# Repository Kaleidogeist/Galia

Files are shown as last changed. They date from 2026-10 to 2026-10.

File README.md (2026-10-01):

# Galia
Modular split ergonomic keyboard system with each half consisting of a central motherboard and a hot-swappable key cluster daughterboard to allow for maximum flexibility.

### Motherboard
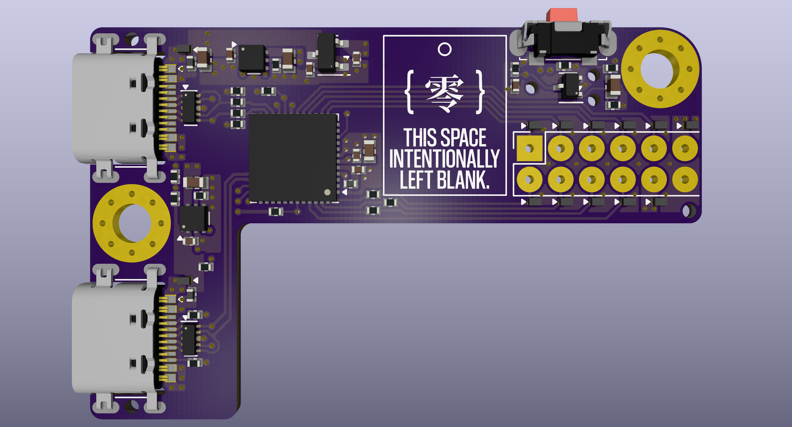
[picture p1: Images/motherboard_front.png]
Motherboard_Front

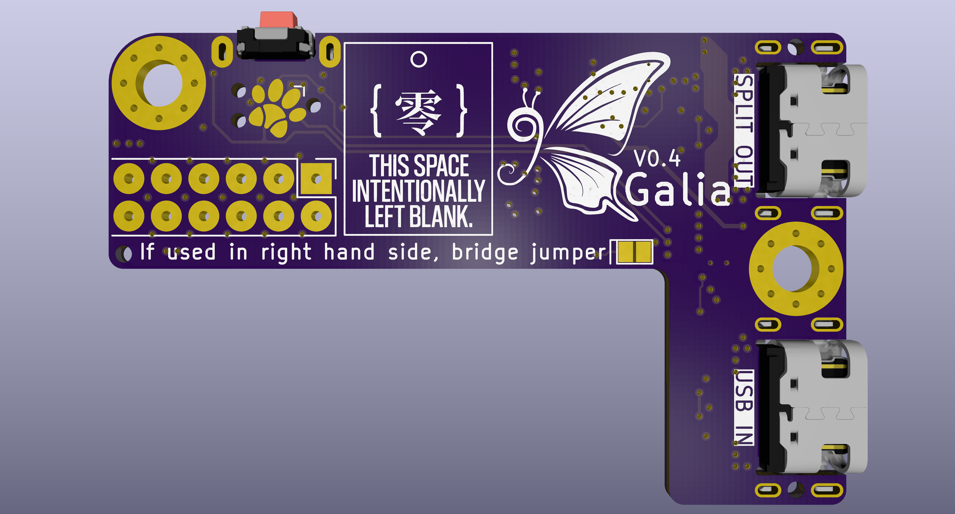
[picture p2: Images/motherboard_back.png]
Motherboard_Back

- Current version: V0.4.
- Schematic [here](https://kicanvas.org/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). 
- Board layout [here](https://kicanvas.org/?repo=https%3A%2F%2Fgithub.com%2Fghostlybutterfly%2FGalia%2Ftree%2FV0_dev%2FMotherboard).
### Daughterboard (Cantaloupe)
Current version: N/A (wip).

## Disclaimer
This keyboard is licensed under [CERN-OHL-S-2.0](https://cern-ohl.web.cern.ch/) and is compatible with both [QMK Firmware](https://qmk.fm/) and [ZMK Firmware](https://zmk.dev).

## Key Features
### Motherboard
* Fully reversible, compact (32.0x50.0mm), and designed to fit onto the top inner corner of a split keyboard.
* On-board STM32G0B1CCU7 processor.
* ESD-protected USB-C input port and USB-C split comms port.
* Connects to daughterboard through fully ESD-protected 2.54mm pitch 02x06 pogo header.
* SPI and USART lines terminated with 22ohm to reduce ringing, overshoot and EMI, and improve signal integrity.
* VBUS input rail limited to ~469mA and 5V output rail limited to ~179mA through the use of TPS2553-1 current limiting switches with reverse voltage protection. VBUS requires power cycling to restart the device upon overcurrent, +5V can be power-cycled through firmware with EN pin controlled through firmware to reduce RGB LED quiescent current draw.
* 4-layer (signal/ground/power/signal) PCB and star ground connection point in between USB port shields.
* [Paw-Connect](https://github.com/LeoDJ/Paw-Connect) TC-2030NL SWD header for debugging purposes.
* On-board single-button reset circuit.
* JLC basic assembly compatible as long as USB ports are not soldered on.

### Daughterboard (TBC)
* Matrix scan planned to be implemented through 74HC595 SIPO shift registers for low power draw and compatibility with ZMK interrupt functionality.
* Also compatible with charlieplex, duplex, and standard matrix layouts.
* WS2812 and AP102 (QMK only) LED support.
* Additional [VIK](https://github.com/sadekbaroudi/vik) header support if desired.

## Pogo header pinout
| Function/description | Pin name | Row 1 | Row 2 | Pin name | Function/description |
| --- | --- | ----- | ----- | --- | --- |
| USART2_TX/ADC1_IN2/TIM2_CH3 | A2 | GPIO1 | CS | B9 | SPI2_NSS/I2C1_SDA/USART3_RX/TIM4_CH4  |
| USART2_RX/ADC1_IN3/TIM2_CH4 | A3 | GPIO2 | SCK | B8 | SPI2_SCK/I2C1_SCL/USART3_TX/TIM4_CH3  |
| SPI1_SCK/ADC1_IN5/TIM2_CH1 | A5 | GPIO3 | MOSI  | B7 | SPI2_MOSI/I2C1_SDA/USART1_RX/TIM4_CH2 |
| SPI1_MISO/ADC1_IN6/I2C2_SDA/TIM3_CH1 | A6 | GPIO4 | MISO  | B6 | SPI2_MISO/I2C1_SCL/USART1_TX/TIM1_CH3 |
| SPI1_MOSI/ADC1_IN7/I2C2_SCL/TIM3_CH2 | A7 | GPIO5 | +5V | N/A | ~207mA max draw by daughterboard |
| 200mA max draw by this side overall  | N/A | VDD | GND | A7 | GND |

## Changelog
* 2026/10/01: Changed library name and updated paths.
* 2026/09/30: V0.4 motherboard update complete. Removed guard ring around the edge of the board. Moved reset button and pogo header down the board. Increased length back to 50mm to allow for an E73-2G4M08S1C version to be developed if desired. Simplified reset circuit - doesn't use the Acheron version anymore. Reduced number of pins in pogo header, as the largest available ones are 2x06. Pinout of pogo header changed to greatly simplify routing - no longer VIK-compliant. Signalis reference and Paw-Connect added back. Changed file structure.
* 2026/09/26: V0.3 motherboard update complete. Reduced size again, rerouted board and changed shape slightly. Removed one mounting hole and centred the other between the USB ports. Changed input fuse and external +5V output to TPS2553-1 latching power switch with reverse voltage/current protection. Removed AO3401 and LMV321 discrete reverse current protection at VBUS input. Reduced size of VBUS and VSPLIT ferrite bead and transistors in the Acheron reset circuit. Made Acheron reset circuit reach DFU faster. 
* 2026/09/21: V0.2 motherboard update complete. Significantly decreased size. GPIO3, GPIO4 and GPIO5 pins changed. Increased size of pogo pin header pads. Removed extra IO header. Replaced 2x03 2.54mm programming header and TC2030-NL with 2x05 1.27mm Samtec IDC header. Replaced reset switch with smaller Alps SKSNLP mid-mount switch. Added layer marker. Changed repository file structure.
* 2026/09/17: Fixed gap in guard rail.
* 2026/09/16: V0.1 motherboard initial commit.

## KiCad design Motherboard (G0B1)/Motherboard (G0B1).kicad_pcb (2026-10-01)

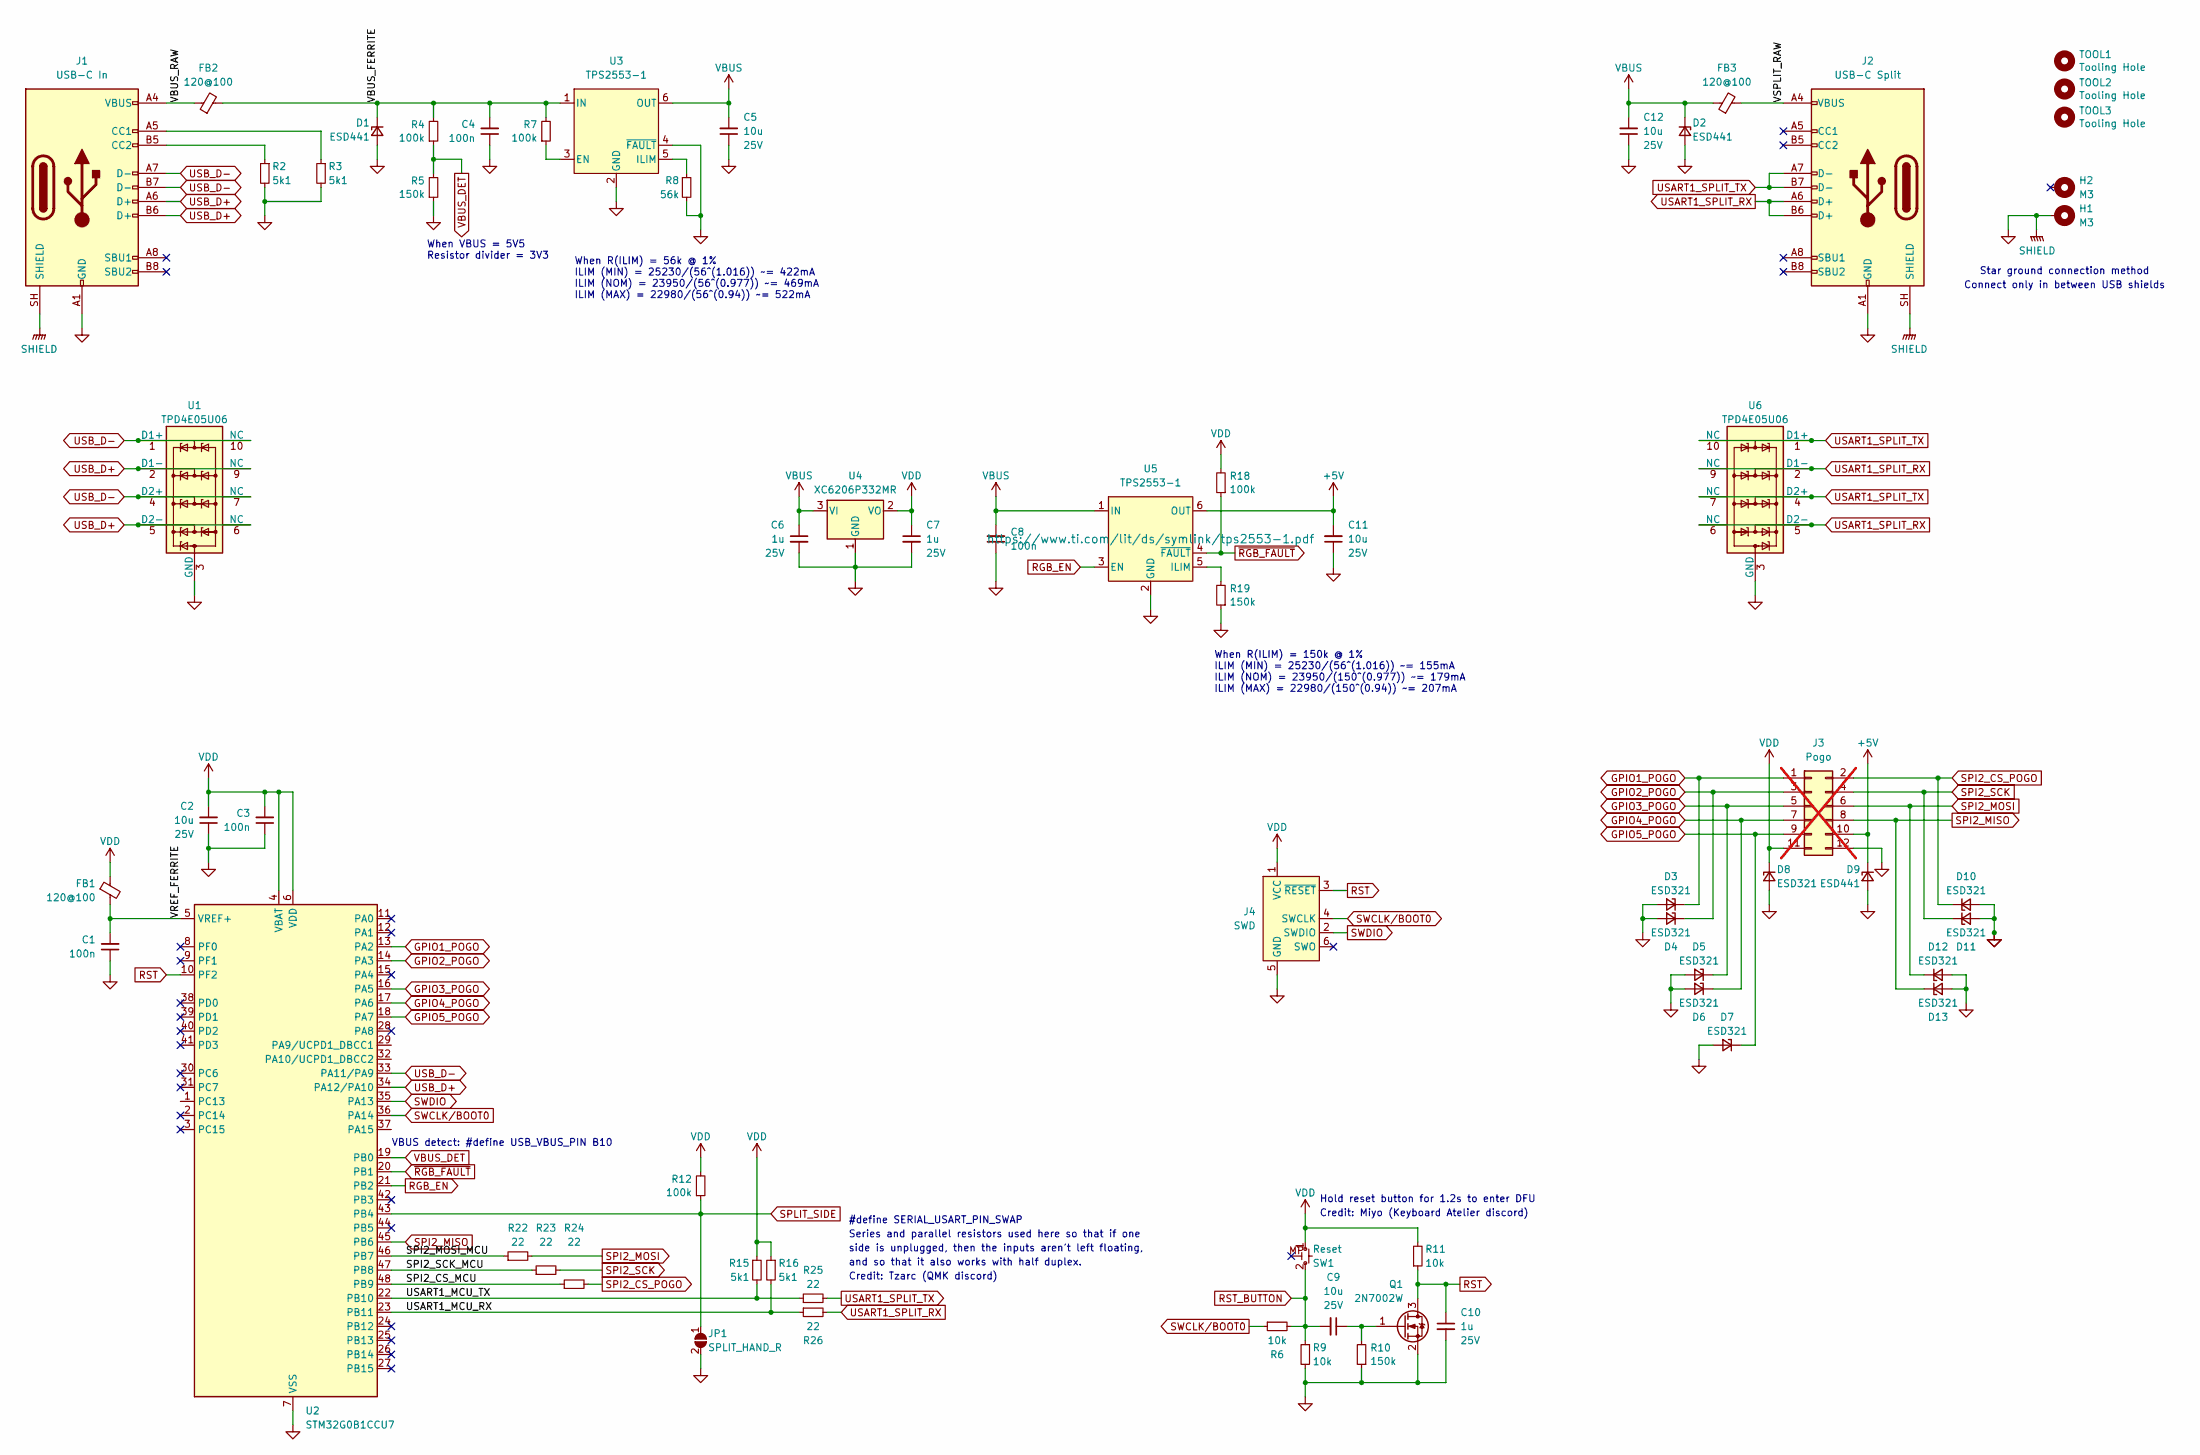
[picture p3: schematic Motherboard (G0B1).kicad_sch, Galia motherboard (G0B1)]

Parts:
C1, C3, C4, C8: 100n; C_0402_1005Metric; Rating 50V; MPN CL05B104KB54PNC; LCSC C307331
C2, C5, C9, C11, C12: 10u; C_0603_1608Metric; Rating 25V; MPN CL10A106MA8NRNC; LCSC C96446
C6, C7, C10: 1u; C_0402_1005Metric; Rating 25V; MPN CL05A105KA5NQNC; LCSC C52923
D1, D2, D9: ESD441; X1SON_0.6x1mm_P0.65mm_Texas_DPY0002A; Rating 7V breakdown; MPN ESD441DPYR; LCSC C53161160
D3, D4, D5, D6, D7, D8, D10, D11, D12, D13: ESD321; X1SON_0.6x1mm_P0.65mm_Texas_DPY0002A; Rating 4V5 breakdown; MPN ESD321DPYR; LCSC C2868952
FB1, FB2, FB3: 120@100; L_0402_1005Metric; MPN MPZ1005S121ET000; LCSC C275477
H1, H2: M3; MountingHole_3.2mm_M3_Pad_Via; MPN N/A; LCSC N/A
J1: USB-C In; USB_C_Receptacle_Molex_2169900001; MPN GT-USB-7014D; LCSC C2843969
J2: USB-C Split; USB_C_Receptacle_Molex_2169900001; MPN GT-USB-7014D; LCSC C2843969
J3: Pogo; PinHeader_2x06_2.54mm_MillMax_PogoTarget_419-10-212-00-0010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; not fitted
J4: SWD; Paw-Connect_RevB_TC2030-IDC-NL_2x03_P1.27mm_Vertical
JP1: SPLIT_HAND_R; SolderJumper-2_P1.2mm_Open_Pad1.0x1.4mm; MPN N/A; LCSC N/A
Q1: 2N7002W; SOT-323_SC-70-3; MPN 2N7002W; LCSC C7420322
R2, R3, R15, R16: 5k1; R_0402_1005Metric; MPN 0402WGF5101TCE; LCSC C25905
R4, R7, R12, R18: 100k; R_0402_1005Metric; MPN 0402WGF1003TCE; LCSC C25741
R5, R10, R19: 150k; R_0402_1005Metric; MPN 0402WGF1503TCE; LCSC C25755
R6, R9, R11: 10k; R_0402_1005Metric; MPN 0402WGF1002TCE; LCSC C25744
R8: 56k; R_0402_1005Metric; MPN 0402WGF5602TCE; LCSC C25796
R22, R23, R24, R25, R26: 22; R_0402_1005Metric; MPN 0402WGF220JTCE; LCSC C25092
SW1: Reset; SW_Alps_SKSNLM_SKSNLP; MPN SKSNLPE010; LCSC C53113391
TOOL1, TOOL2, TOOL3: Tooling Hole; MountingHole_JLC-Tooling; MPN N/A; LCSC N/A
U1, U6: TPD4E05U06; USON-10_2.5x1.0mm_P0.5mm; MPN TPD4E05U06QDQARQ1; LCSC C81353
U2: STM32G0B1CCU7; QFN-48-1EP_7x7mm_P0.5mm_EP5.6x5.6mm; MPN STM32G0B1CCU7; LCSC C29759424
U3, U5: TPS2553-1; WSON-6-1EP_2x2mm_P0.65mm_EP1x1.6mm; MPN TPS2553DRVR-1; LCSC C411878
U4: XC6206P332MR; SOT-23-3; MPN XC6206P332MR-G; LCSC C5446

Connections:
+5V: C11.2, D9.1 (K), J3.10, U5.6 (OUT)
/SPI2_CS_MCU: R24.1, U2.48 (PB9)
/SPI2_MOSI_MCU: R22.1, U2.46 (PB7)
/SPI2_SCK_MCU: R23.1, U2.47 (PB8)
/USART1_MCU_RX: R16.2, R26.1, U2.23 (PB11)
/USART1_MCU_TX: R15.2, R25.1, U2.22 (PB10)
/VBUS_FERRITE: C4.2, D1.1 (K), FB2.2, R4.2, R7.2, U3.1 (IN)
/VBUS_RAW: FB2.1, J1.A4 (VBUS), J1.A9 (VBUS), J1.B4 (VBUS), J1.B9 (VBUS)
/VREF_FERRITE: C1.2, FB1.2, U2.5 (VREF+)
/VSPLIT_RAW: FB3.2, J2.A4 (VBUS), J2.A9 (VBUS), J2.B4 (VBUS), J2.B9 (VBUS)
GND: C1.1, C2.1, C3.1, C4.1, C5.1, C6.2, C7.2, C8.1, C10.2, C11.1, C12.1, D1.2 (A), D2.2 (A), D3.2 (A), D4.2 (A), D5.2 (A), D6.2 (A), D7.2 (A), D8.2 (A), D9.2 (A), D10.2 (A), D11.2 (A), D12.2 (A), D13.2 (A), H1.1 (1_1), J1.A1 (GND), J1.A12 (GND), J1.B1 (GND), J1.B12 (GND), J1.SH (SHIELD), J2.A1 (GND), J2.A12 (GND), J2.B1 (GND), J2.B12 (GND), J2.SH (SHIELD), J3.12, J4.5 (GND), JP1.2 (B), Q1.2 (S), R2.2, R3.2, R5.1, R8.2, R9.2, R10.1, R19.1, U1.3 (GND), U1.8 (GND), U2.7 (VSS), U2.49 (VSS), U3.2 (GND), U3.4 (~FAULT), U3.7 (EP), U4.1 (GND), U5.2 (GND), U5.7 (EP), U6.3 (GND), U6.8 (GND)
GPIO1_POGO: D3.1 (K), J3.1, U2.13 (PA2)
GPIO2_POGO: D4.1 (K), J3.3, U2.14 (PA3)
GPIO3_POGO: D5.1 (K), J3.5, U2.16 (PA5)
GPIO4_POGO: D6.1 (K), J3.7, U2.17 (PA6)
GPIO5_POGO: D7.1 (K), J3.9, U2.18 (PA7)
unnamed: J1.A5 (CC1), R3.1
unnamed: J1.B5 (CC2), R2.1
unnamed: C9.1, Q1.1 (G), R10.2
unnamed: R7.1, U3.3 (EN)
unnamed: R8.1, U3.5 (ILIM)
unnamed: R19.2, U5.5 (ILIM)
RGB_EN: U2.21 (PB2), U5.3 (EN)
RST: C10.1, J4.3 (~RESET), Q1.3 (D), R11.1, U2.10 (PF2)
RST_BUTTON: C9.2, R6.2, R9.1, SW1.2 (B)
SPI2_CS_POGO: D10.1 (K), J3.2, R24.2
SPI2_MISO: D13.1 (K), J3.8, U2.45 (PB6)
SPI2_MOSI: D12.1 (K), J3.6, R22.2
SPI2_SCK: D11.1 (K), J3.4, R23.2
SPLIT_SIDE: JP1.1 (A), R12.1, U2.43 (PB4)
SWCLK/BOOT0: J4.4 (SWCLK), R6.1, U2.36 (PA14)
SWDIO: J4.2 (SWDIO), U2.35 (PA13)
USART1_SPLIT_RX: J2.A6 (D+), J2.B6 (D+), R26.2, U6.2 (D1-), U6.5 (D2-), U6.6 (NC), U6.9 (NC)
USART1_SPLIT_TX: J2.A7 (D-), J2.B7 (D-), R25.2, U6.1 (D1+), U6.4 (D2+), U6.7 (NC), U6.10 (NC)
USB_D+: J1.A6 (D+), J1.B6 (D+), U1.2 (D1-), U1.5 (D2-), U1.6 (NC), U1.9 (NC), U2.34 (PA12/PA10)
USB_D-: J1.A7 (D-), J1.B7 (D-), U1.1 (D1+), U1.4 (D2+), U1.7 (NC), U1.10 (NC), U2.33 (PA11/PA9)
VBUS: C5.2, C6.1, C8.2, C12.2, D2.1 (K), FB3.1, U3.6 (OUT), U4.3 (VI), U5.1 (IN)
VBUS_DET: R4.1, R5.2, U2.19 (PB0)
VDD: C2.2, C3.2, C7.1, D8.1 (K), FB1.1, J3.11, J4.1 (VCC), R11.2, R12.2, R15.1, R16.1, R18.2, SW1.1 (A), U2.4 (VBAT), U2.6 (VDD), U4.2 (VO)
~RGB_FAULT: R18.1, U2.20 (PB1), U5.4 (~FAULT)

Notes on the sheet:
When R(ILIM) = 56k @ 1% ILIM (MIN) = 25230/(56^(1.016)) ~= 422mA ILIM (NOM) = 23950/(56^(0.977)) ~= 469mA ILIM (MAX) = 22980/(56^(0.94)) ~= 522mA
Credit: Tzarc (QMK discord)
Hold reset button for 1.2s to enter DFU
Series and parallel resistors used here so that if one
VBUS detect: #define USB_VBUS_PIN B10
Credit: Miyo (Keyboard Atelier discord)
side is unplugged, then the inputs aren't left floating,
and so that it also works with half duplex.
When VBUS = 5V5 Resistor divider = 3V3
Connect only in between USB shields
#define SERIAL_USART_PIN_SWAP
When R(ILIM) = 150k @ 1% ILIM (MIN) = 25230/(56^(1.016)) ~= 155mA ILIM (NOM) = 23950/(150^(0.977)) ~= 179mA ILIM (MAX) = 22980/(150^(0.94)) ~= 207mA
Star ground connection method

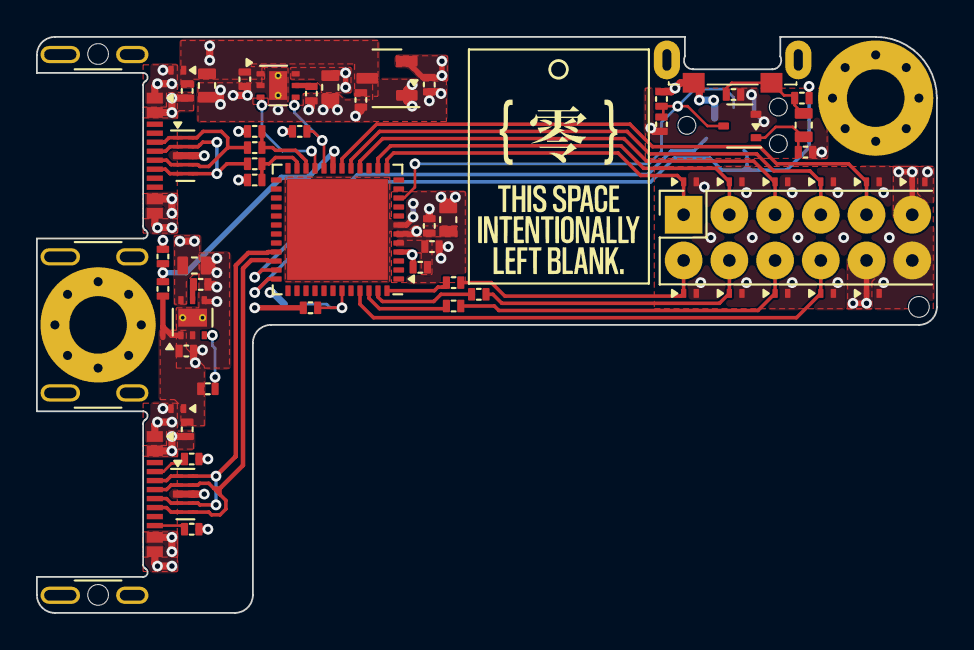
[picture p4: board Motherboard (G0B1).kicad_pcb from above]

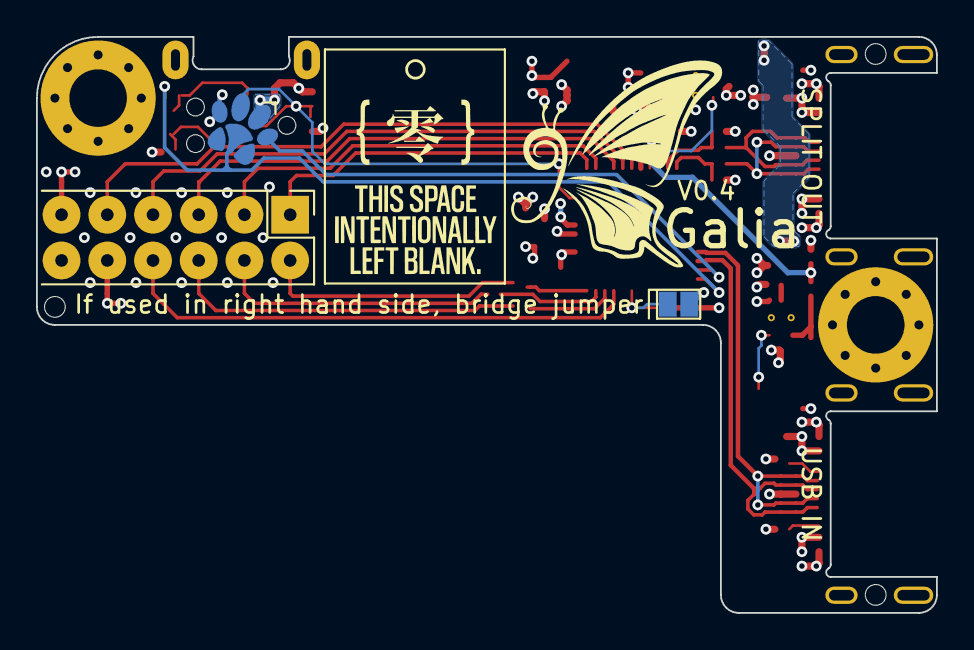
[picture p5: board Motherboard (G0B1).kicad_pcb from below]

Board: 4 copper layers, 50.0 x 32.0 mm, 66 parts (2 on the bottom side), 40 nets.

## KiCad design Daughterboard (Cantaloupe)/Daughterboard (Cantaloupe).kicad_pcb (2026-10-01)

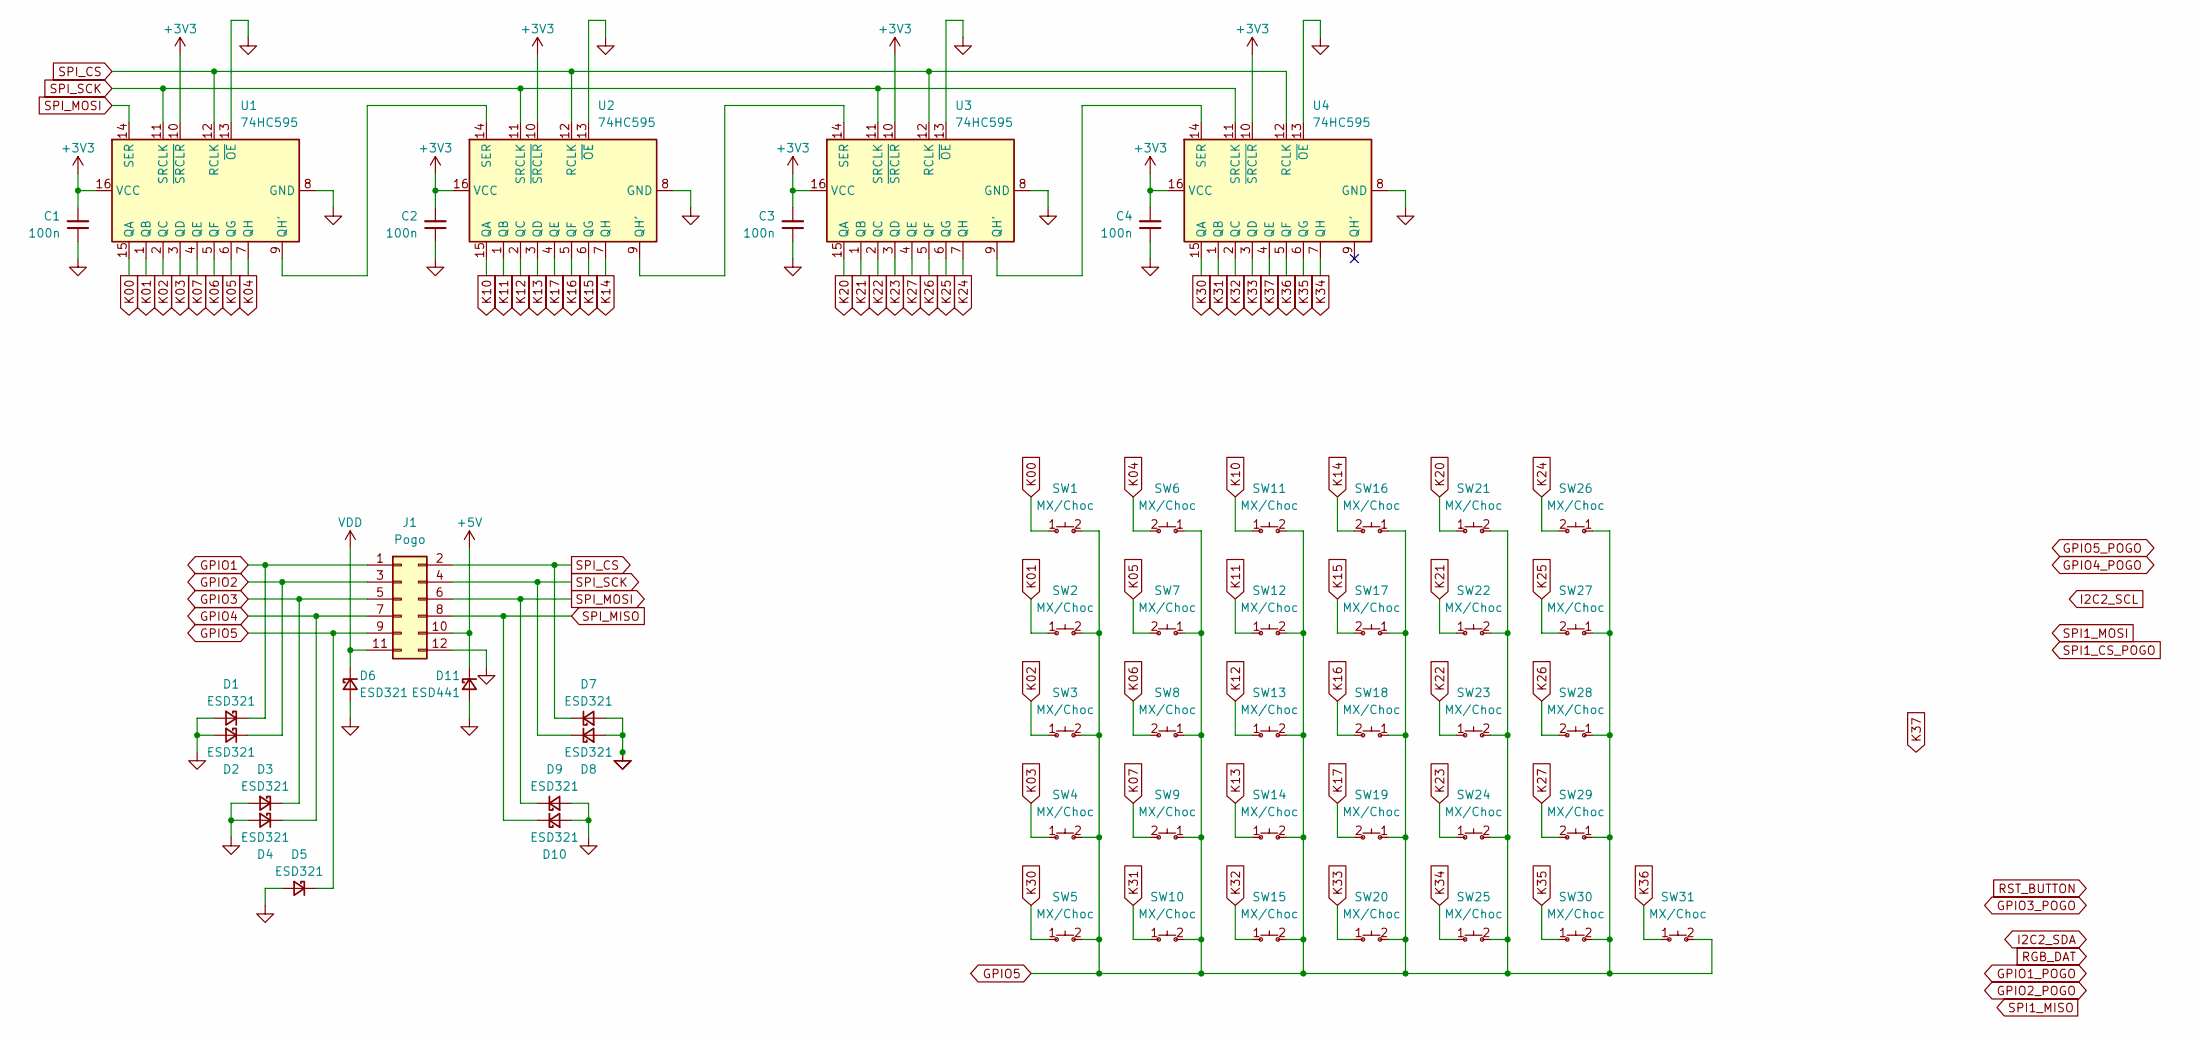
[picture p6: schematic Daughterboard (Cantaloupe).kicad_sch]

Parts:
C1, C2, C3, C4: 100n; C_0402_1005Metric; Voltage 50V; MPN CL05B104KB54PNC; LCSC C307331
D1, D2, D3, D4, D5, D6, D7, D8, D9, D10: ESD321; X1SON_0.6x1mm_P0.65mm_Texas_DPY0002A; Rating 4V5 breakdown; MPN ESD321DPYR; LCSC C2868952
D11: ESD441; X1SON_0.6x1mm_P0.65mm_Texas_DPY0002A; Rating 7V breakdown; MPN ESD441DPYR; LCSC C53161160
J1: Pogo; PinHeader_2x06_2.54mm_MillMax_PogoPin_823-22-012-10-000101-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
SW1, SW2, SW3, SW4, SW5, SW6, SW7, SW8, SW9, SW10, SW11, SW12, SW13, SW14, SW15, SW16, SW17, SW18, SW19, SW20, SW21, SW22, SW23, SW24, SW25, SW26, SW27, SW28, SW29, SW30, SW31: MX/Choc; SW_KB_Choc-KS33_1U_Hotswap_Reversible
U1, U2, U3, U4: 74HC595; DHVQFN-16-1EP_2.5x3.5mm_P0.5mm_EP1x2mm; MPN 74HC595BQ,115; LCSC C730243

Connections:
+3V3: C1.2, C2.2, C3.2, C4.2, U1.10 (~SRCLR), U1.16 (VCC), U2.10 (~SRCLR), U2.16 (VCC), U3.10 (~SRCLR), U3.16 (VCC), U4.10 (~SRCLR), U4.16 (VCC)
+5V: D11.1 (K), J1.10
GND: C1.1, C2.1, C3.1, C4.1, D1.2 (A), D2.2 (A), D3.2 (A), D4.2 (A), D5.2 (A), D6.2 (A), D7.2 (A), D8.2 (A), D9.2 (A), D10.2 (A), D11.2 (A), J1.12, U1.8 (GND), U1.13 (~OE), U1.17 (EP), U2.8 (GND), U2.13 (~OE), U2.17 (EP), U3.8 (GND), U3.13 (~OE), U3.17 (EP), U4.8 (GND), U4.13 (~OE), U4.17 (EP)
GPIO1: D1.1 (K), J1.1
GPIO2: D2.1 (K), J1.3
GPIO3: D3.1 (K), J1.5
GPIO4: D4.1 (K), J1.7
GPIO5: D5.1 (K), J1.9, SW1.2 (B), SW2.2 (B), SW3.2 (B), SW4.2 (B), SW5.2 (B), SW6.1 (A), SW7.1 (A), SW8.1 (A), SW9.1 (A), SW10.2 (B), SW11.2 (B), SW12.2 (B), SW13.2 (B), SW14.2 (B), SW15.2 (B), SW16.1 (A), SW17.1 (A), SW18.1 (A), SW19.1 (A), SW20.2 (B), SW21.2 (B), SW22.2 (B), SW23.2 (B), SW24.2 (B), SW25.2 (B), SW26.1 (A), SW27.1 (A), SW28.1 (A), SW29.1 (A), SW30.2 (B), SW31.2 (B); also elsewhere on the board
K00: SW1.1 (A), U1.15 (QA); also elsewhere on the board
K01: SW2.1 (A), U1.1 (QB)
K02: SW3.1 (A), U1.2 (QC)
K03: SW4.1 (A), U1.3 (QD)
K04: SW6.2 (B), U1.7 (QH)
K05: SW7.2 (B), U1.6 (QG)
K06: SW8.2 (B), U1.5 (QF)
K07: SW9.2 (B), U1.4 (QE)
K10: SW11.1 (A), U2.15 (QA)
K11: SW12.1 (A), U2.1 (QB)
K12: SW13.1 (A), U2.2 (QC)
K13: SW14.1 (A), U2.3 (QD)
K14: SW16.2 (B), U2.7 (QH)
K15: SW17.2 (B), U2.6 (QG)
K16: SW18.2 (B), U2.5 (QF)
K17: SW19.2 (B), U2.4 (QE)
K20: SW21.1 (A), U3.15 (QA)
K21: SW22.1 (A), U3.1 (QB)
K22: SW23.1 (A), U3.2 (QC)
K23: SW24.1 (A), U3.3 (QD)
K24: SW26.2 (B), U3.7 (QH)
K25: SW27.2 (B), U3.6 (QG)
K26: SW28.2 (B), U3.5 (QF)
K27: SW29.2 (B), U3.4 (QE)
K30: SW5.1 (A), U4.15 (QA)
K31: SW10.1 (A), U4.1 (QB)
K32: SW15.1 (A), U4.2 (QC)
K33: SW20.1 (A), U4.3 (QD)
K34: SW25.1 (A), U4.7 (QH)
K35: SW30.1 (A), U4.6 (QG)
K36: SW31.1 (A), U4.5 (QF)
K37: U4.4 (QE)
unnamed: U1.9 (QH'), U2.14 (SER)
unnamed: U2.9 (QH'), U3.14 (SER)
unnamed: U3.9 (QH'), U4.14 (SER)
SPI_CS: D7.1 (K), J1.2, U1.12 (RCLK), U2.12 (RCLK), U3.12 (RCLK), U4.12 (RCLK)
SPI_MISO: D10.1 (K), J1.8
SPI_MOSI: D9.1 (K), J1.6, U1.14 (SER)
SPI_SCK: D8.1 (K), J1.4, U1.11 (SRCLK), U2.11 (SRCLK), U3.11 (SRCLK), U4.11 (SRCLK)
VDD: D6.1 (K), J1.11

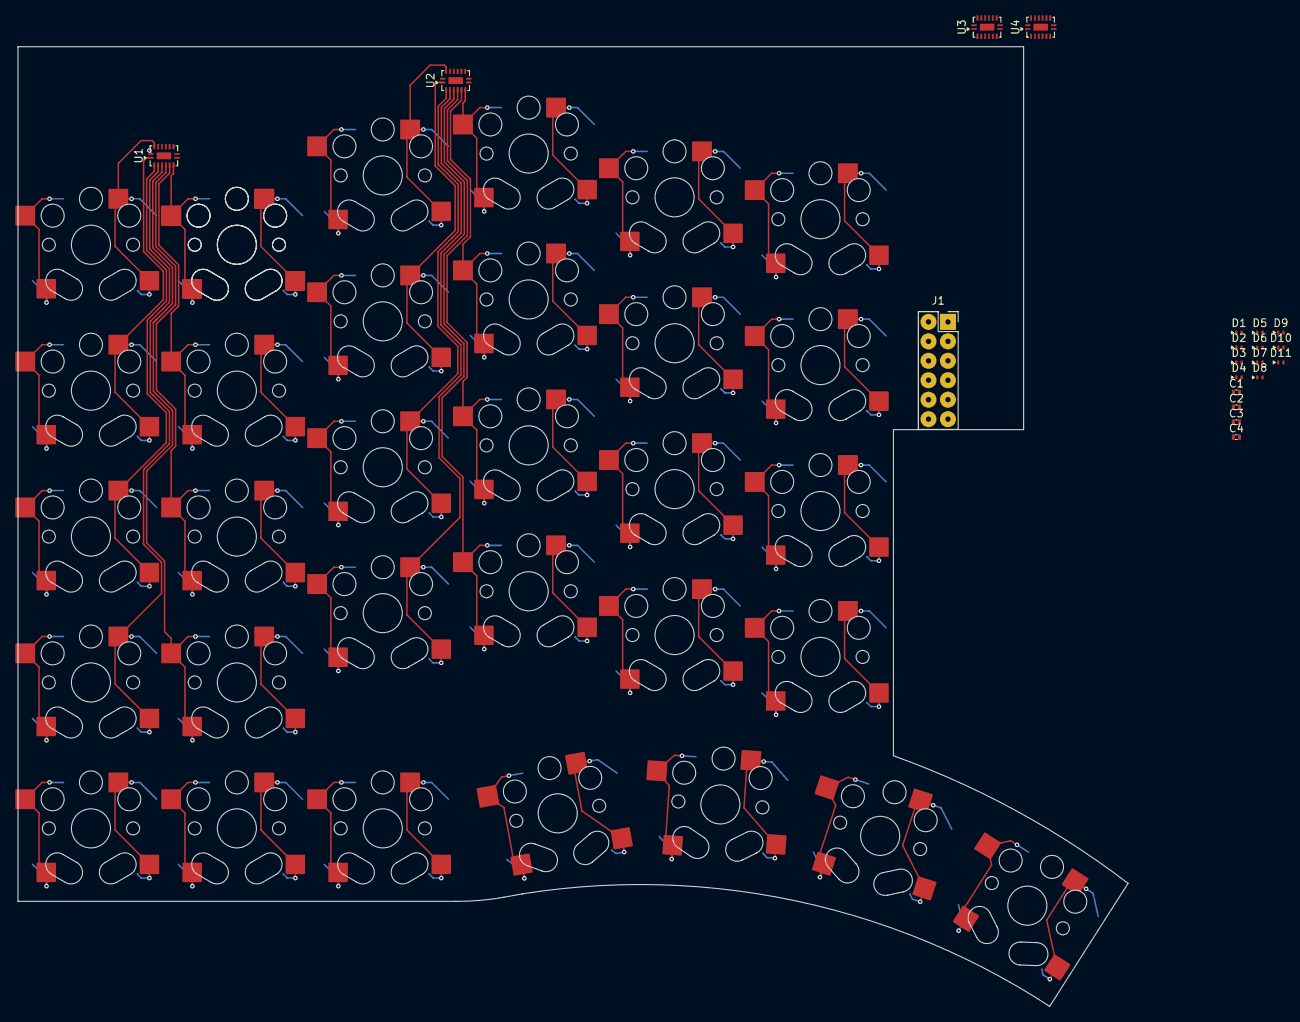
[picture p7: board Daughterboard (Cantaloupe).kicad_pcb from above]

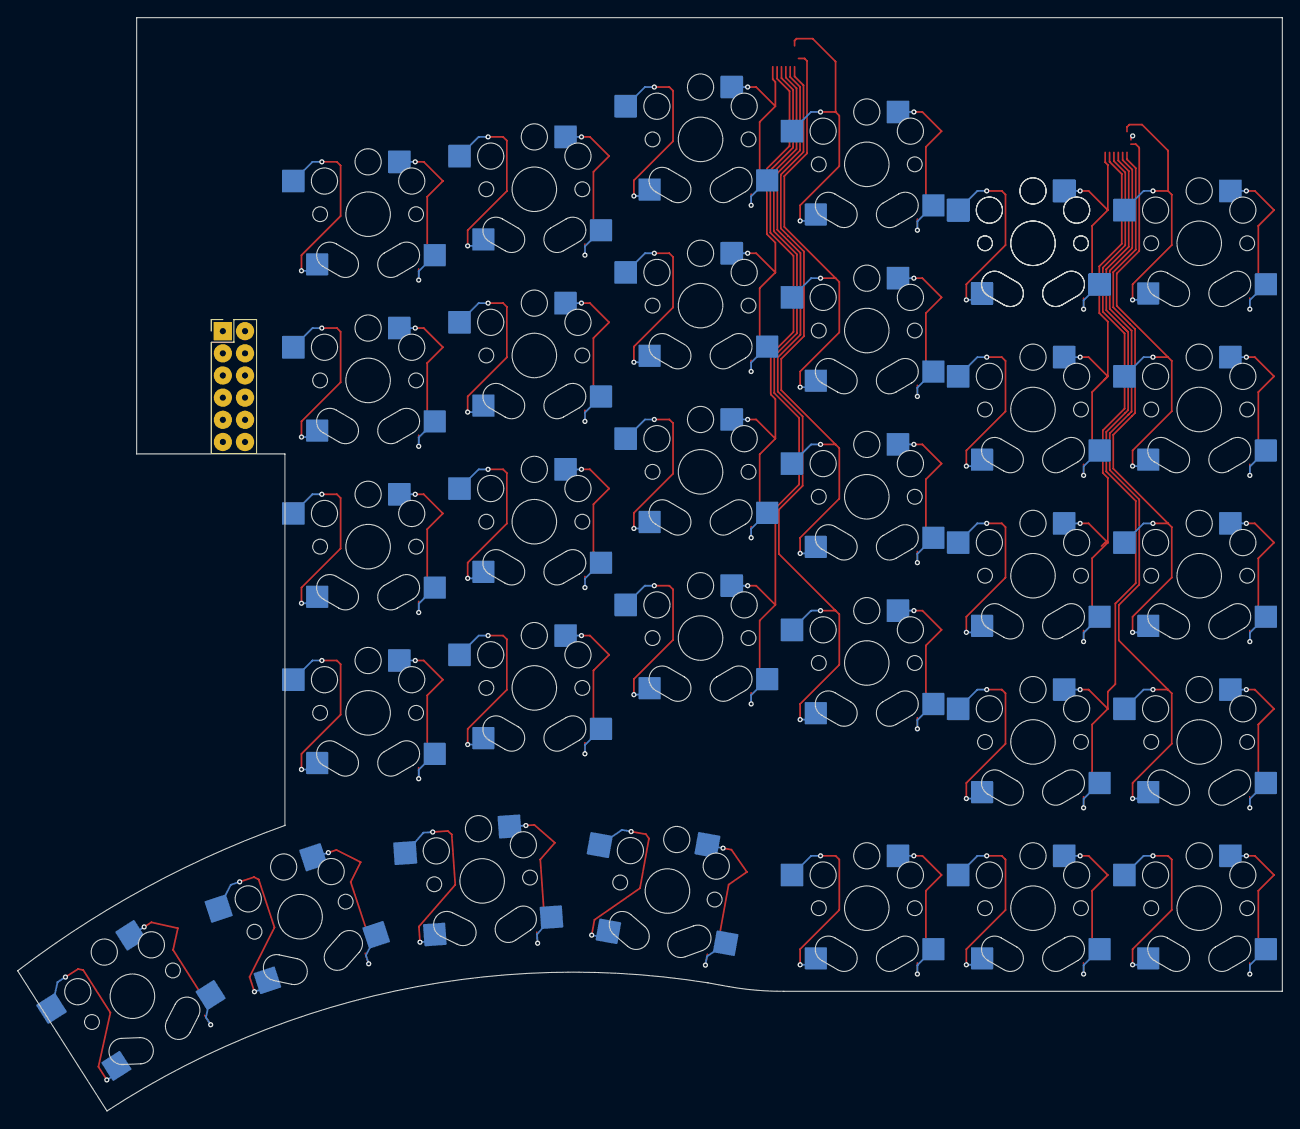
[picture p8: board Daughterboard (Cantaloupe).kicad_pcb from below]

Board: 2 copper layers, 144.9 x 125.3 mm, 52 parts (32 on the bottom side), 47 nets.

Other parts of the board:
SW1#2: MX/Choc; SW_KB_Choc-KS33_1U_Hotswap_Reversible

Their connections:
GPIO5: SW1#2.2 (B); also elsewhere on the board
K00: SW1#2.1 (A); also elsewhere on the board

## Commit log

2026-10-01 2026/09/30: V0.4 motherboard update complete
    Removed guard ring around the edge of the board. Moved reset button and pogo header down the board. Increased length back to 50mm to allow for an E73-2G4M08S1C version to be developed if desired. Simplified reset circuit - doesn't use the Acheron version anymore. Reduced number of pins in pogo header, as the largest available ones are 2x06. Pinout of pogo header changed to greatly simplify routing - no longer VIK-compliant. Signalis reference and Paw-Connect added back. Changed file structure.
    [Daughterboard (Cantaloupe).kicad_pcb, Daughterboard (Cantaloupe).kicad_sch, Motherboard (G0B1).kicad_pcb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]
2026-10-01 2026/10/01: Changed library name and updated paths
    [Daughterboard (Cantaloupe).kicad_pcb, Daughterboard (Cantaloupe).kicad_sch, Motherboard (G0B1).kicad_pcb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]
